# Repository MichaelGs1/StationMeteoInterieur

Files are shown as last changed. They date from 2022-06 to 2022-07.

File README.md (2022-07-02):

# StationMeteoInterieur

<p align="justify">&ensp;&ensp;Projet d'une station méteo permettant de surveiller la température, l'humidité, le taux de CO2 ainsi que le total de particules nocives TVOC. Il permet également de détecter les fumées.
Toutes ces informations sont indiquées sur un écran LCD et des leds informent l'utilisateur d'un taux trop élévés de particules, de CO2 ou de fumée.</p>

### Matériel necéssaire:

- Capteurs :
  - DHT22 (température, humidité)
  - CSS811 (CO2, TVOC)
  - MQ-2 (fumées)
  
- Un écran LCD 4 lignes, 20 caractères en I2C

- Arduino : Nano BLE ou Nano 33 IOT

- Leds 5mm : rouge, verte, bleu

- Transistors : 2 BSS138
- Résistances CMS (0805 imperial) : 3x100Ohms, 4x10kOhms
- Résistance tranversante : 10kOhms
- Condensateurs tranversants : 100uF

- Connecteurs : PinSockets pas de 2.54mm de diverses longueurs

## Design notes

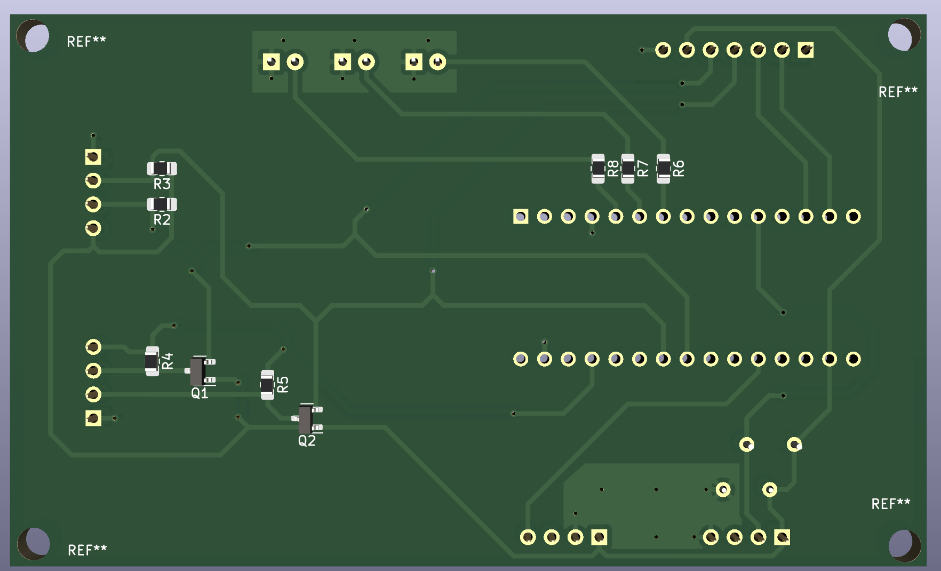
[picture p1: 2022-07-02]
PCB_Back.png

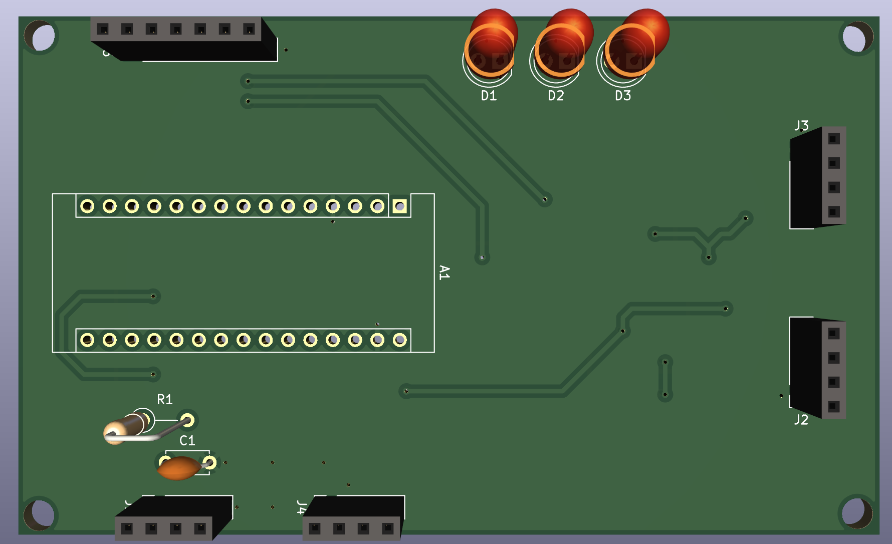
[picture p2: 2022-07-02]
PCB_Front.png

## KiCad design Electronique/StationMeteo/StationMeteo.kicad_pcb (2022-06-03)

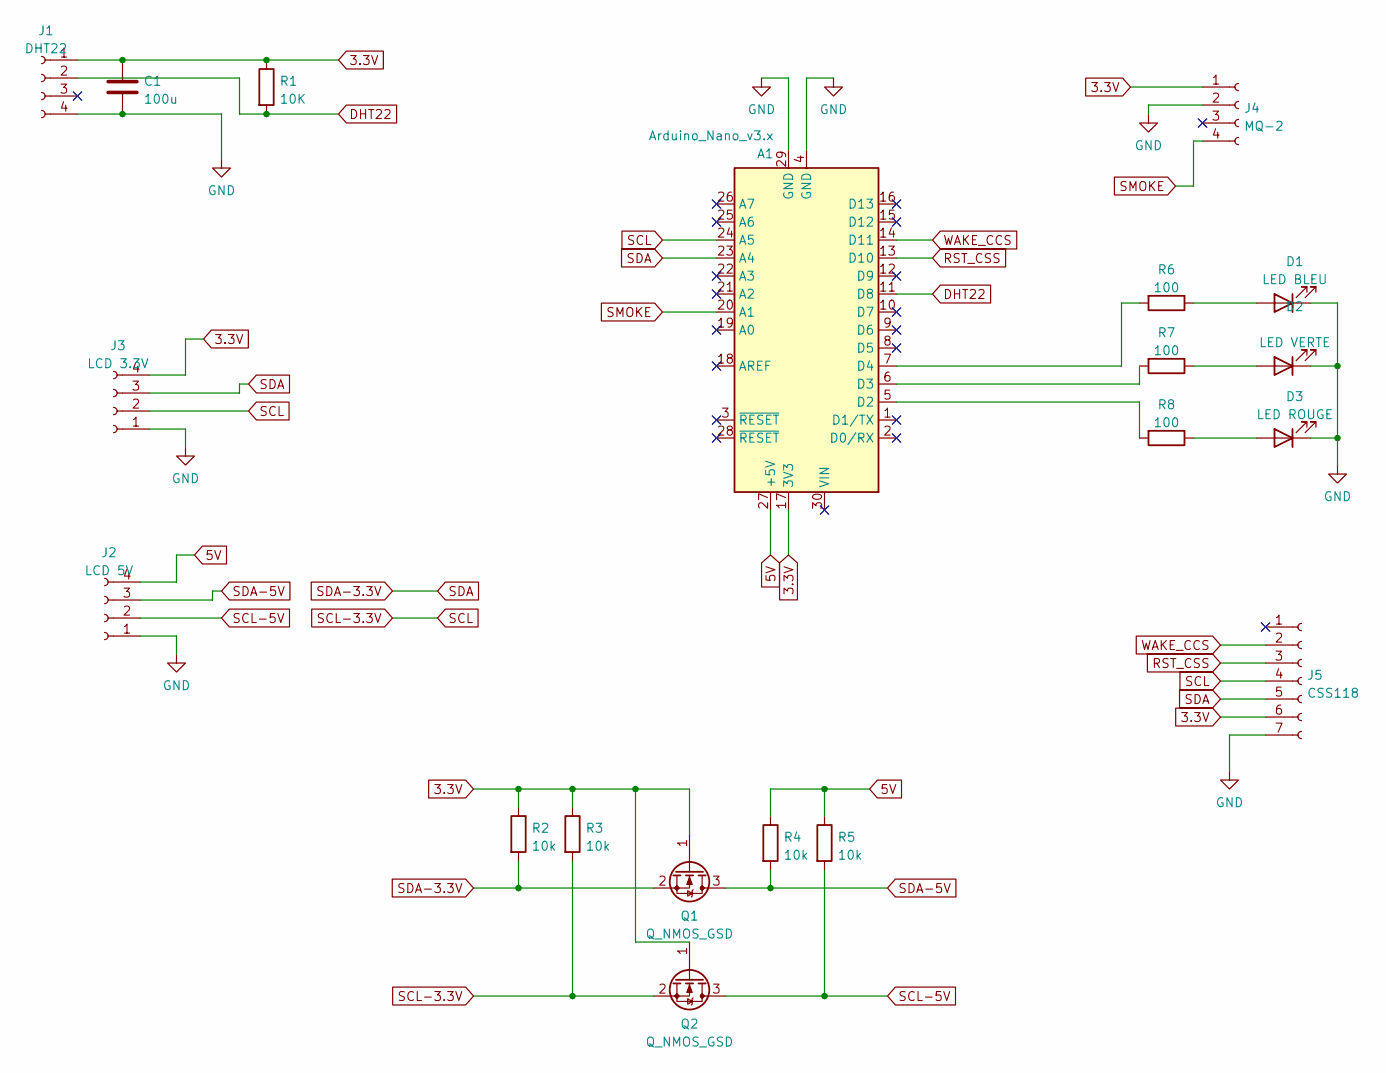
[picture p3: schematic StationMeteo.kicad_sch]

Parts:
A1: Arduino_Nano_v3.x; Arduino_Nano
C1: 100u; C_Disc_D4.7mm_W2.5mm_P5.00mm
D1: LED BLEU; LED_D5.0mm
D2: LED VERTE; LED_D5.0mm
D3: LED ROUGE; LED_D5.0mm
J1: DHT22; PinSocket_1x04_P2.54mm_Vertical
J2: LCD 5V; PinSocket_1x04_P2.54mm_Vertical
J3: LCD 3.3V; PinSocket_1x04_P2.54mm_Vertical
J4: MQ-2; PinSocket_1x04_P2.54mm_Vertical
J5: CSS118; PinSocket_1x07_P2.54mm_Vertical
Q1, Q2: Q_NMOS_GSD; SOT-23
R1: 10K; R_Axial_DIN0207_L6.3mm_D2.5mm_P5.08mm_Vertical
R2, R3, R4, R5: 10k; R_0805_2012Metric_Pad1.20x1.40mm_HandSolder
R6, R7, R8: 100; R_0805_2012Metric_Pad1.20x1.40mm_HandSolder

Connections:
3.3V: A1.17 (3V3), C1.1, J1.1, J3.4, J4.1, J5.6, Q1.1 (G), Q2.1 (G), R1.1, R2.1, R3.1
5V: A1.27 (+5V), J2.4, R4.1, R5.1
DHT22: A1.11 (D8), J1.2, R1.2
GND: A1.4 (GND), A1.29 (GND), C1.2, D1.1 (K), D2.1 (K), D3.1 (K), J1.4, J2.1, J3.1, J4.2, J5.7
unnamed: A1.5 (D2), R8.2
unnamed: A1.6 (D3), R7.2
unnamed: A1.7 (D4), R6.2
unnamed: D1.2 (A), R6.1
unnamed: D2.2 (A), R7.1
unnamed: D3.2 (A), R8.1
RST_CSS: A1.13 (D10), J5.3
SCL: A1.24 (A5), J3.2, J5.4, Q2.2 (S), R3.2
SCL-5V: J2.2, Q2.3 (D), R5.2
SDA: A1.23 (A4), J3.3, J5.5, Q1.2 (S), R2.2
SDA-5V: J2.3, Q1.3 (D), R4.2
SMOKE: A1.20 (A1), J4.4
WAKE_CCS: A1.14 (D11), J5.2

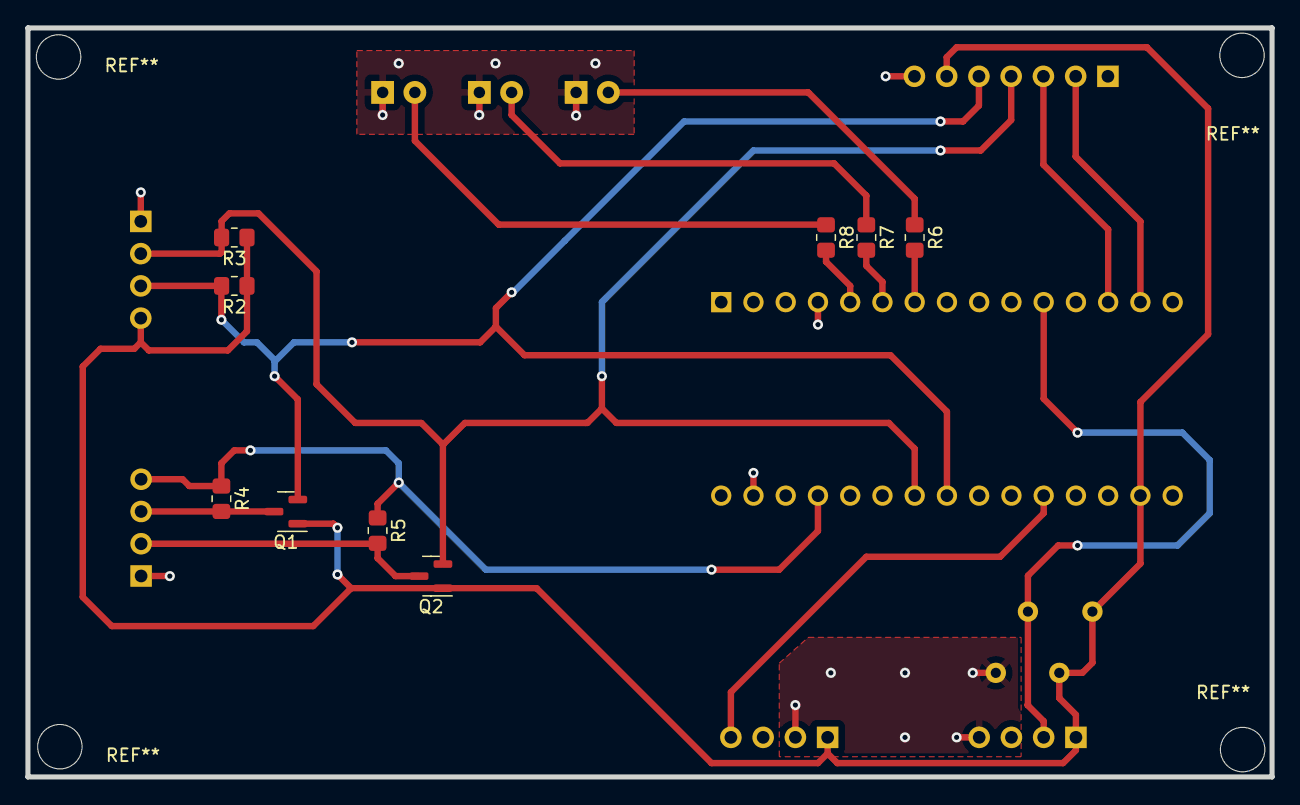
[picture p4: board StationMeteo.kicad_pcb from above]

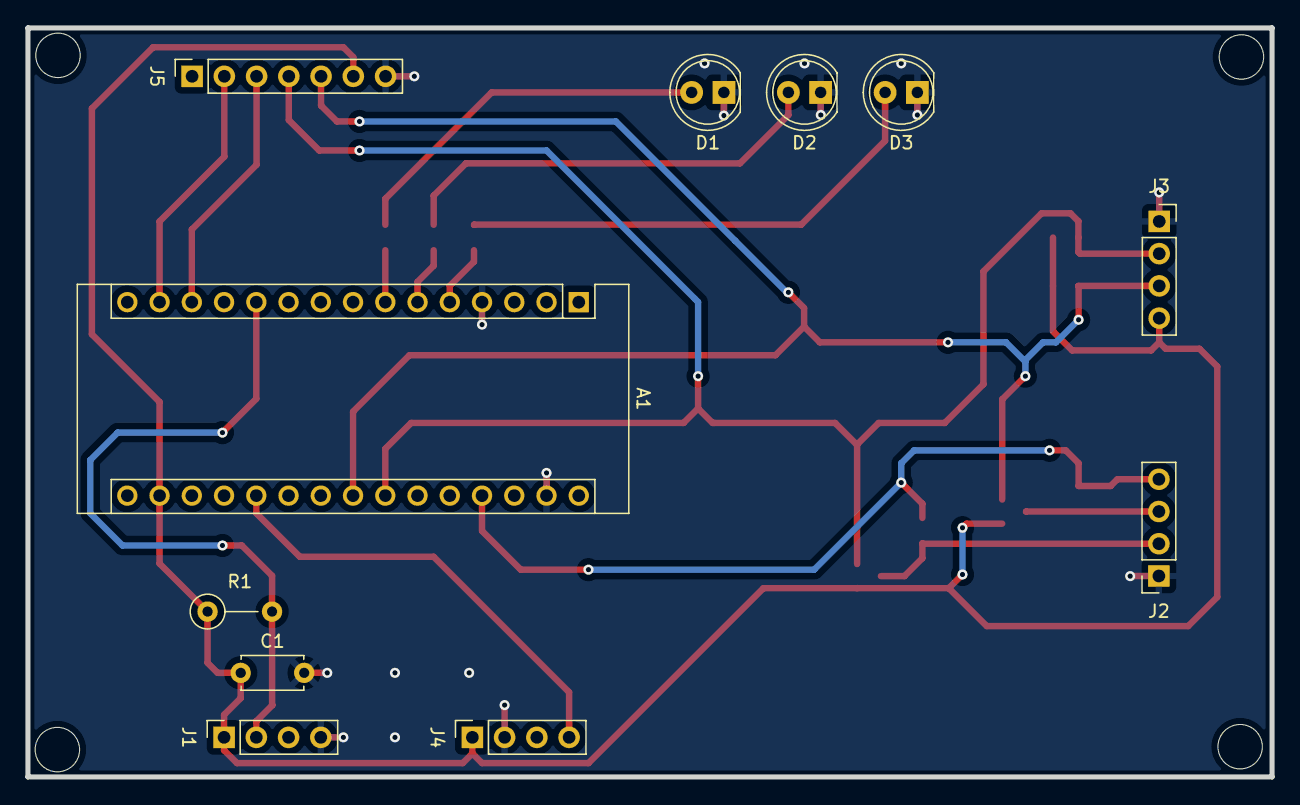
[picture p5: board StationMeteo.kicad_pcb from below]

Board: 2 copper layers, 98.0 x 59.0 mm, 20 parts (11 on the bottom side), 17 nets.

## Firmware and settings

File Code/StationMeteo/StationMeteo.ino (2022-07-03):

#include <Wire.h> 
#include <LiquidCrystal_I2C.h>
#include <Adafruit_Sensor.h>
#include <DHT.h>
#include <DHT_U.h>
#include <Adafruit_CCS811.h>

// Commenter si debug off
//#define DEBUG

// Pins
#define DHTPIN 8
#define DHTTYPE DHT22     
#define SMOKE A1

#define redLed 2
#define greenLed 3
#define blueLed 4

#define TIME_REFRESH_TEMP_CCS811 60000

// Instances
DHT_Unified dht(DHTPIN, DHTTYPE);
Adafruit_CCS811 ccs;
LiquidCrystal_I2C lcd(0x27,20,4);  // set the LCD address to 0x27 for a 16 chars and 2 line display


// Prototypes
void displayAt(int col, int row, String text);
void resetLine(int row);
void initDHT();
void initCSS();
void initSMOKE();
void initLed();
void getTempHumi(double &temp, double &humidity);
void readCSS(double &eCO2, double &TVOC);
int getSMOKE();

// Variables
uint32_t delayReadDHT;
unsigned long realTime;
unsigned long oldRealTime;

unsigned long timeRefreshCCS811;
unsigned long oldTimeRefreshCCS811;

int smokeThreshold = 800;
float co2Threshold = 750;
float tvocThreshold = 10;

void setup() 
{
  #ifdef DEBUG
    while(!Serial)
    Serial.begin(9600);
  #endif
  //lcd
  lcd.init();
  lcd.backlight();
  //DHT22 (Temperature, Humidity)
  initLed();
  initDHT();
  initCSS();
  initSMOKE();
}

void loop() 
{
  // Read DHT
  realTime = millis();
  if (realTime - oldRealTime > delayReadDHT)
  {
    oldRealTime = realTime;
    double temp, humidity;
    getTempHumi(temp, humidity);
    if (temp != -1 && humidity != -1)
    {
      resetLine(0);
      resetLine(1);
      displayAt(0, 0, "Temp:");
      displayAt(6, 0, String(temp));
      displayAt(11, 0, "C");
      
      displayAt(0, 1, "Humi:");
      displayAt(6, 1, String(humidity));
      displayAt(11, 1, "%");

      if (timeRefreshCCS811 - oldTimeRefreshCCS811 > TIME_REFRESH_TEMP_CCS811)
      {
        ccs.setEnvironmentalData(humidity, temp);
      }
    }
  }

  // Read CSS
  if(ccs.available())
  {
    double eCO2, TVOC;
    readCSS(eCO2, TVOC);
    if (eCO2 != -1)
    {
      resetLine(2);
      resetLine(3);
      displayAt(0, 2, "eCO2:");
      displayAt(5, 2, String(eCO2));
      displayAt(0, 3, "TVOC:");
      displayAt(5, 3, String(TVOC));
    }

    // Threshold
    if (eCO2 > co2Threshold)
      digitalWrite(blueLed, HIGH);
    else
      digitalWrite(blueLed, LOW);

    if (TVOC > tvocThreshold)
      digitalWrite(greenLed, HIGH);
    else
      digitalWrite(greenLed, LOW);
  }

  // Read Smoke
  int smoke = getSMOKE();
  if (smoke > smokeThreshold)
  {
    digitalWrite(redLed, HIGH);
    delay(3000);
    lcd.clear();
    displayAt(2, 1,"Attention fumee");
    displayAt(2, 2, "detectee");
    delay(3000);
    lcd.clear();
  }
  else
  {
    digitalWrite(redLed, LOW);
  }
}

void initDHT()
{
  dht.begin();
  sensor_t sensor;
  dht.temperature().getSensor(&sensor);
  #ifdef DEBUG
    Serial.println(F("------------------------------------"));
    Serial.println(F("Temperature Sensor"));
    Serial.print  (F("Sensor Type: ")); Serial.println(sensor.name);
    Serial.print  (F("Driver Ver:  ")); Serial.println(sensor.version);
    Serial.print  (F("Unique ID:   ")); Serial.println(sensor.sensor_id);
    Serial.print  (F("Max Value:   ")); Serial.print(sensor.max_value); Serial.println(F("°C"));
    Serial.print  (F("Min Value:   ")); Serial.print(sensor.min_value); Serial.println(F("°C"));
    Serial.print  (F("Resolution:  ")); Serial.print(sensor.resolution); Serial.println(F("°C"));
    Serial.println(F("------------------------------------"));
  #endif
  dht.humidity().getSensor(&sensor);
  #ifdef DEBUG
    Serial.println(F("Humidity Sensor"));
    Serial.print  (F("Sensor Type: ")); Serial.println(sensor.name);
    Serial.print  (F("Driver Ver:  ")); Serial.println(sensor.version);
    Serial.print  (F("Unique ID:   ")); Serial.println(sensor.sensor_id);
    Serial.print  (F("Max Value:   ")); Serial.print(sensor.max_value); Serial.println(F("%"));
    Serial.print  (F("Min Value:   ")); Serial.print(sensor.min_value); Serial.println(F("%"));
    Serial.print  (F("Resolution:  ")); Serial.print(sensor.resolution); Serial.println(F("%"));
    Serial.println(F("------------------------------------"));
  #endif
  // Set delay between sensor readings based on sensor details.
  delayReadDHT = sensor.min_delay / 1000;
}

void initCSS()
{
  pinMode(10, OUTPUT);
  digitalWrite(10, HIGH);
  pinMode(11, OUTPUT);
  digitalWrite(11, LOW);
  if(!ccs.begin())
  {
    #ifdef DEBUG
      Serial.println("Failed to start sensor! Please check your wiring.");
    #endif
    while(1);
  }
  while(!ccs.available());
}

void initSMOKE()
{
  pinMode(SMOKE, INPUT);
}

void initLed()
{
  pinMode(redLed, OUTPUT);
  pinMode(greenLed, OUTPUT);
  pinMode(blueLed, OUTPUT);

  digitalWrite(redLed, HIGH);
  digitalWrite(greenLed, HIGH);
  digitalWrite(blueLed, HIGH);
}

void getTempHumi(double &temp, double &humidity)
{
  sensors_event_t event;
  dht.temperature().getEvent(&event);
  if (isnan(event.temperature))
  {
    #ifdef DEBUG
      Serial.println(F("Error reading temperature!"));
    #endif
    temp = -1;
  }
  else 
  {
    temp = event.temperature;
    #ifdef DEBUG
      Serial.print(F("Temperature: "));
      Serial.print(temp);
      Serial.println(F("°C"));
    #endif
  }
  // Get humidity event and print its value.
  dht.humidity().getEvent(&event);
  if (isnan(event.relative_humidity)) 
  {
    #ifdef DEBUG
      Serial.println(F("Error reading humidity!"));
    #endif
    humidity = -1;
  }
  else 
  {
    humidity = event.relative_humidity;
    #ifdef DEBUG
      Serial.print(F("Humidity: "));
      Serial.print(humidity);
      Serial.println(F("%"));
    #endif
  }
}

void readCSS(double &eCO2, double &TVOC)
{
  if(!ccs.readData())
  {
    eCO2 = ccs.geteCO2();
    TVOC = ccs.getTVOC();

    #ifdef DEBUG
      Serial.print("CO2: ");
      Serial.print(eCO2);
      Serial.print("ppm, TVOC: ");
      Serial.println(TVOC);
    #endif
  }
  else
  {
    eCO2 = -1;
    TVOC = -1;
    #ifdef DEBUG
      Serial.println("ERROR!");
      while(1);
    #endif
  }
}

int getSMOKE()
{
  int smoke = analogRead(SMOKE);
  #ifdef DEBUG
    Serial.print("Smoke: ");
    Serial.println(smoke);
  #endif
  return smoke;
}

void resetLine(int row)
{
  for (int i = 0; i < 20; ++i)
  {
    displayAt(i, row, " ");
  }
}

void displayAt(int col, int row, String text)
{
  lcd.setCursor(col, row);
  lcd.print(text);
}

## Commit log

2022-06-03 init file
    [StationMeteo-B_Cu.gbl, StationMeteo-B_Mask.gbs, StationMeteo-B_Silkscreen.gbo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]
2022-07-02 add temp and humi to polution sensor
2022-07-02 fix prototypes
